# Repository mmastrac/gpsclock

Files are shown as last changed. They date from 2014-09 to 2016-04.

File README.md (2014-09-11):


========

Simple GPS clock project based on simple components from Adafruit and eBay. This consists of a number of components:

  * A backpack for the Adafruit KWA-221 2.3" digit based on the TLC-5920NT (KiCad PCB project)
  
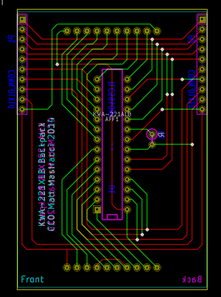
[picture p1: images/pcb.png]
pcb screenshot


  * An Arduino project that reads GPS time from the Adafruit GPS adapter and pushes it out to backpack

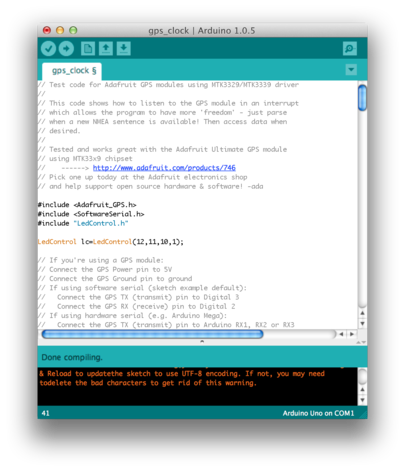
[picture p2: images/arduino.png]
arduino screenshot


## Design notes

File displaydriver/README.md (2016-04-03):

This is the AVR code that runs the display driver

The attiny85 can be programmed like so, note the lfuse settings for the external clock:

make clean && make && avrdude -p t85 -c avrispv2 -P /dev/cu.usbmodem00028541 -U flash:w:main.hex -U lfuse:w:0xe2:m

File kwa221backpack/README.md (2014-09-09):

TODO:

  * Contribute TLC-5940NT back to open-projects
  * Move all routed traces underneath footprint of LED

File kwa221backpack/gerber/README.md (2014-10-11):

These are the files you submit to the board manufacturing service.

v1
==

Original, manufactured via Seeedstudios. 

Deficiencies:
  * No mounting holes
  * Headers hit the lip on the LED display, making it tough to align
  * No way to easily test value of IREF resistor when using trim pots

v2
==

(in progress)

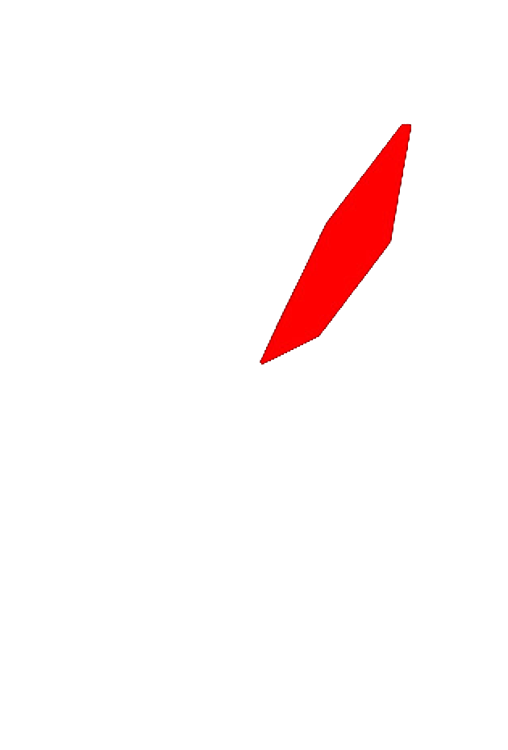
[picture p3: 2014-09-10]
fontmaker/display/K.png

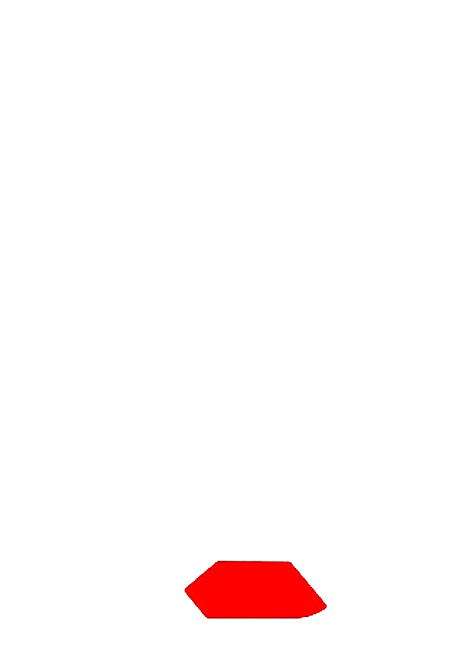
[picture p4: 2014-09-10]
fontmaker/display/D2.png

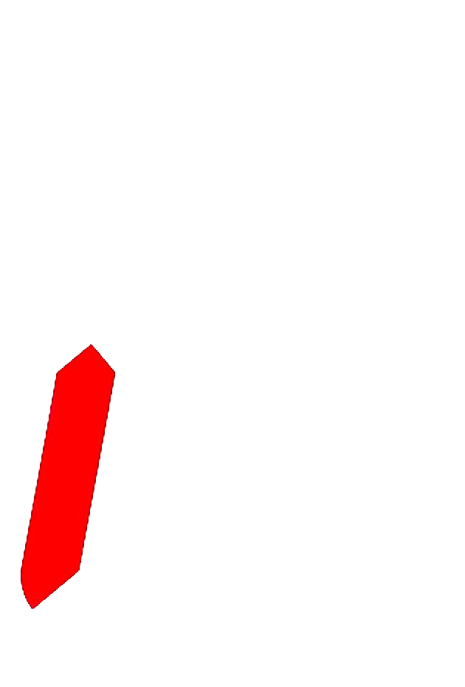
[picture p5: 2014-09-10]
fontmaker/display/E.png

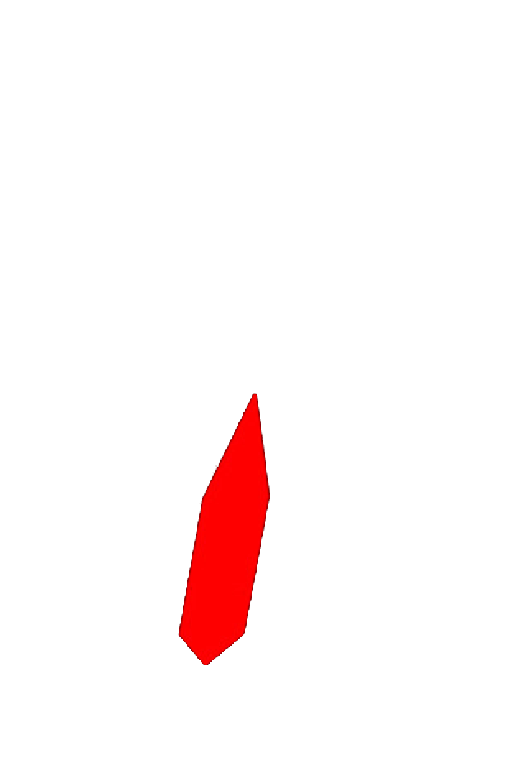
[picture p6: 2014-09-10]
fontmaker/display/M.png

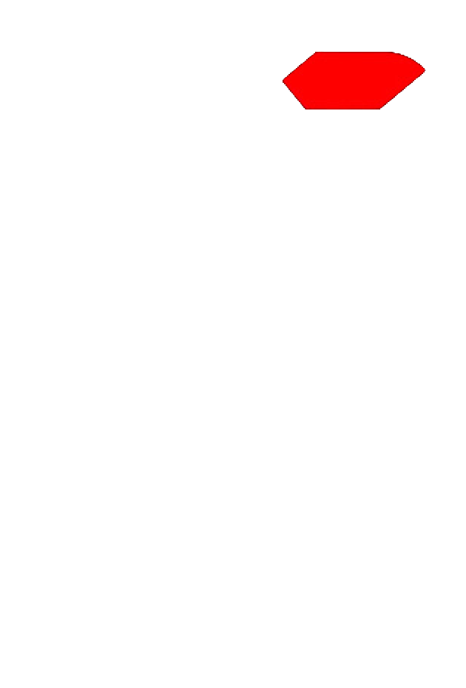
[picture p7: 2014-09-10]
fontmaker/display/A2.png

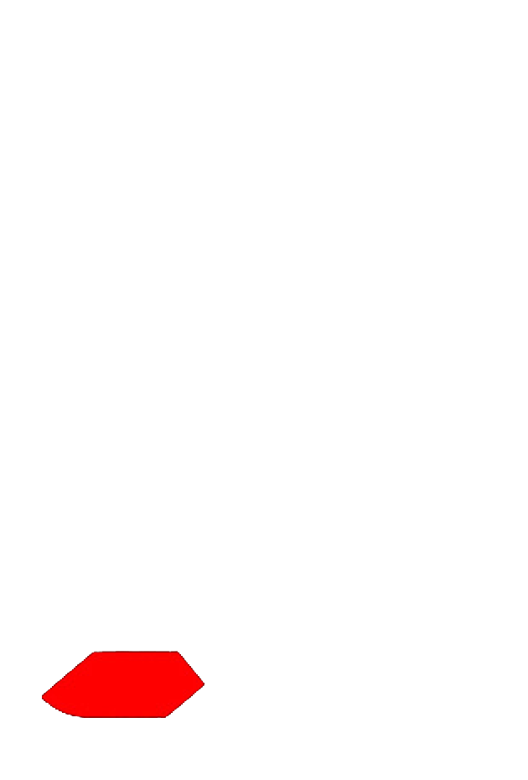
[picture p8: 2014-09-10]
fontmaker/display/D1.png

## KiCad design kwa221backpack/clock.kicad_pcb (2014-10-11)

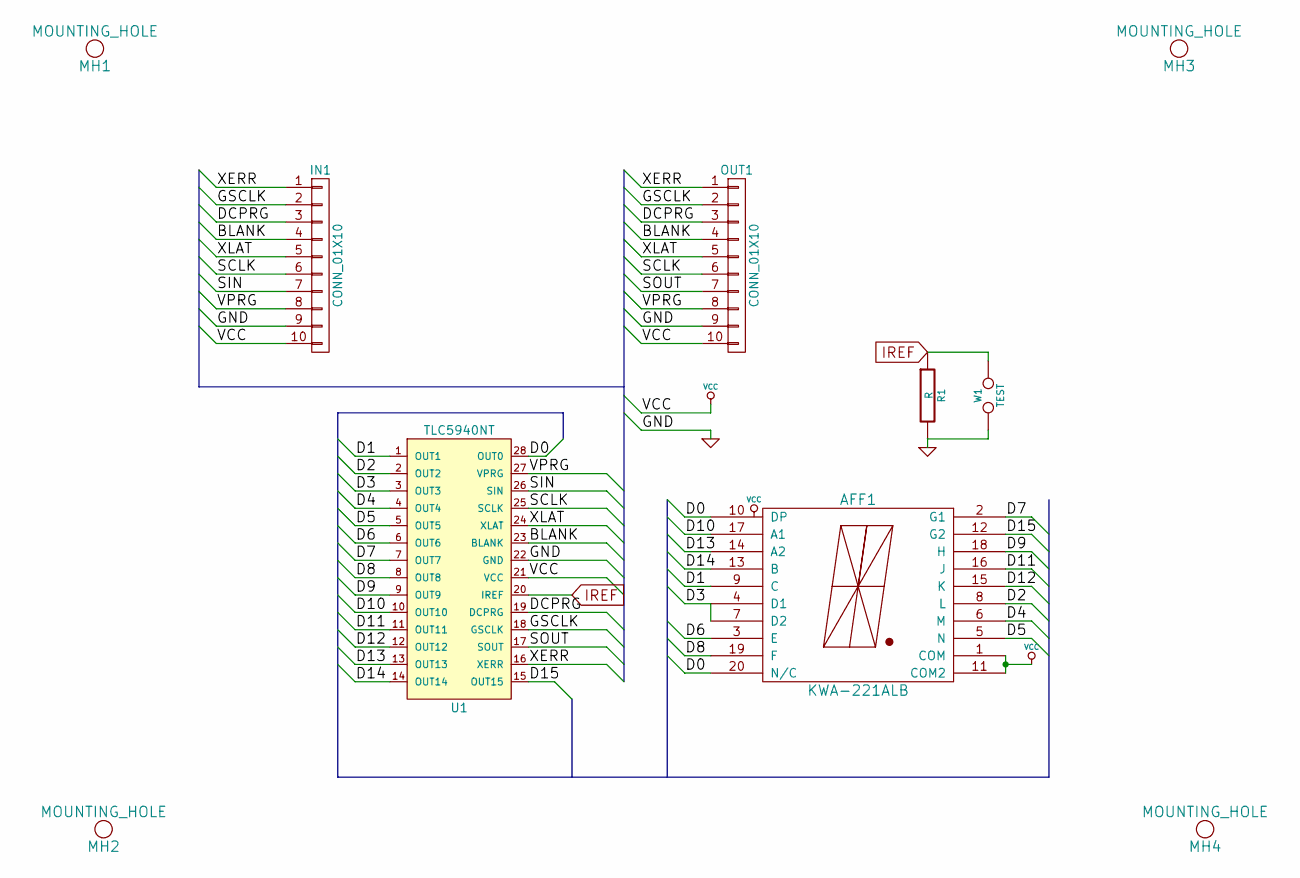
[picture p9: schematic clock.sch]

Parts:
AFF1: KWA-221ALB
IN1: CONN_01X10
MH1, MH2, MH3, MH4: MOUNTING_HOLE
OUT1: CONN_01X10
R1: R
U1: TLC5940NT
W1: TEST

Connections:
/BLANK: IN1.4, OUT1.4, U1.23 (BLANK)
/D0: AFF1.10 (DP), AFF1.20 (N/C), U1.28 (OUT0)
/D1: AFF1.9 (C), U1.1 (OUT1)
/D2: AFF1.8 (L), U1.2 (OUT2)
/D3: AFF1.4 (D1), AFF1.7 (D2), U1.3 (OUT3)
/D4: AFF1.6 (M), U1.4 (OUT4)
/D5: AFF1.5 (N), U1.5 (OUT5)
/D6: AFF1.3 (E), U1.6 (OUT6)
/D7: AFF1.2 (G1), U1.7 (OUT7)
/D8: AFF1.19 (F), U1.8 (OUT8)
/D9: AFF1.18 (H), U1.9 (OUT9)
/D10: AFF1.17 (A1), U1.10 (OUT10)
/D11: AFF1.16 (J), U1.11 (OUT11)
/D12: AFF1.15 (K), U1.12 (OUT12)
/D13: AFF1.14 (A2), U1.13 (OUT13)
/D14: AFF1.13 (B), U1.14 (OUT14)
/D15: AFF1.12 (G2), U1.15 (OUT15)
/DCPRG: IN1.3, OUT1.3, U1.19 (DCPRG)
/GSCLK: IN1.2, OUT1.2, U1.18 (GSCLK)
/SCLK: IN1.6, OUT1.6, U1.25 (SCLK)
/SIN: IN1.7, U1.26 (SIN)
/SOUT: OUT1.7, U1.17 (SOUT)
/VPRG: IN1.8, OUT1.8, U1.27 (VPRG)
/XERR: IN1.1, OUT1.1, U1.16 (XERR)
/XLAT: IN1.5, OUT1.5, U1.24 (XLAT)
GND: IN1.9, OUT1.9, R1.2, U1.22 (GND), W1.1
IREF: R1.1, U1.20 (IREF), W1.2
VCC: AFF1.1 (COM), AFF1.11 (COM2), IN1.10, OUT1.10, U1.21 (VCC)

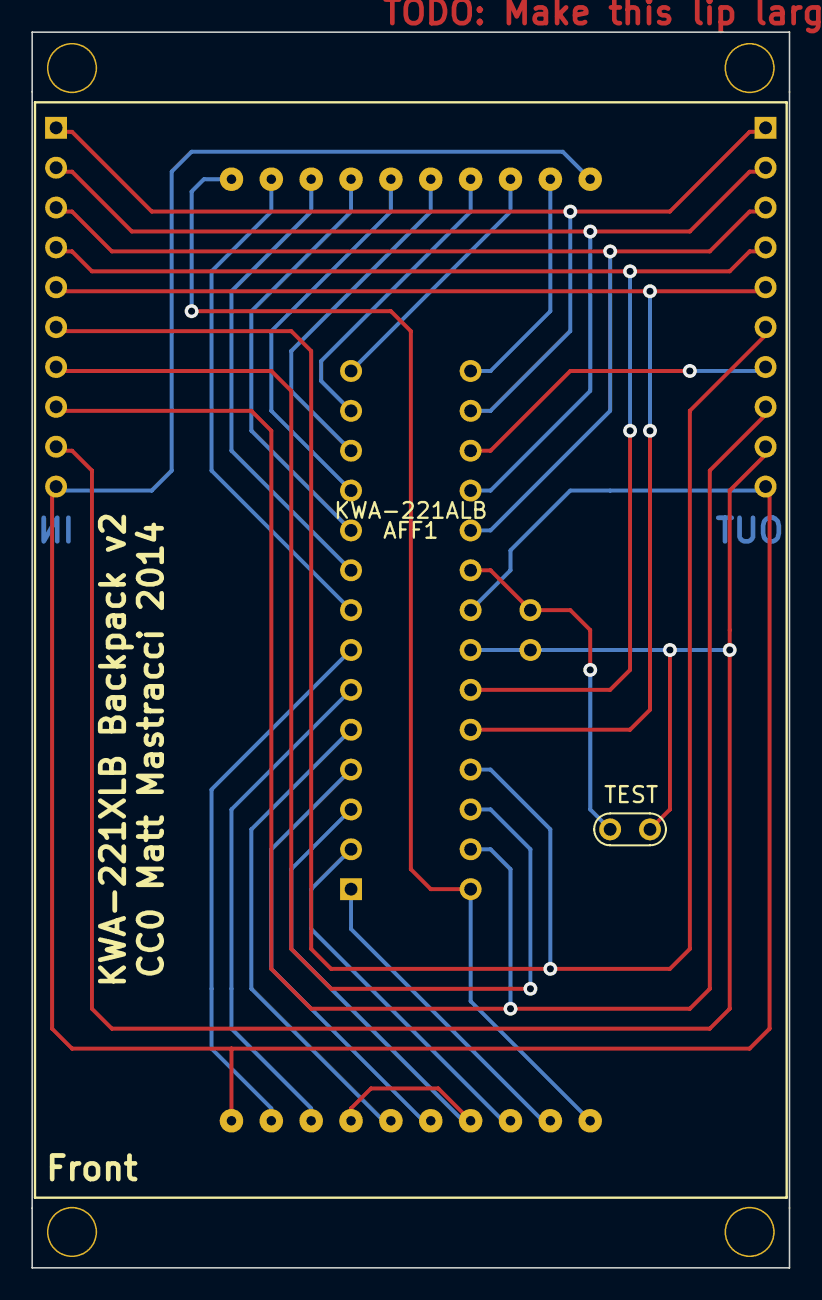
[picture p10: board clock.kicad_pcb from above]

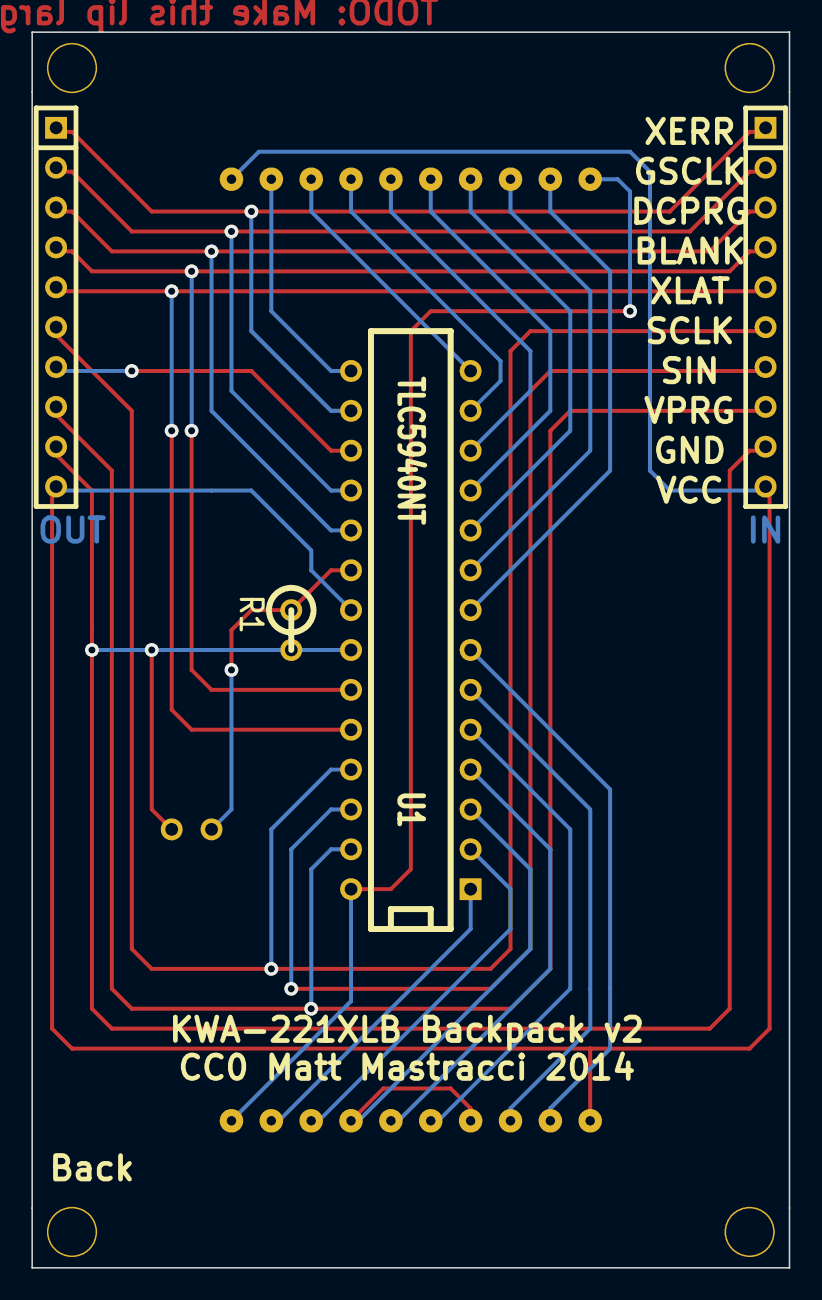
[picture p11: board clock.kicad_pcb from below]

Board: 2 copper layers, 48.3 x 78.7 mm, 10 parts (4 on the bottom side), 28 nets.

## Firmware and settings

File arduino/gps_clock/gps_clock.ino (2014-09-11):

// Test code for Adafruit GPS modules using MTK3329/MTK3339 driver
//
// This code shows how to listen to the GPS module in an interrupt
// which allows the program to have more 'freedom' - just parse
// when a new NMEA sentence is available! Then access data when
// desired.
//
// Tested and works great with the Adafruit Ultimate GPS module
// using MTK33x9 chipset
//    ------> http://www.adafruit.com/products/746
// Pick one up today at the Adafruit electronics shop 
// and help support open source hardware & software! -ada

#include <Adafruit_GPS.h>
#include <SoftwareSerial.h>
#include "LedControl.h"

LedControl lc=LedControl(12,11,10,1);

// If you're using a GPS module:
// Connect the GPS Power pin to 5V
// Connect the GPS Ground pin to ground
// If using software serial (sketch example default):
//   Connect the GPS TX (transmit) pin to Digital 3
//   Connect the GPS RX (receive) pin to Digital 2
// If using hardware serial (e.g. Arduino Mega):
//   Connect the GPS TX (transmit) pin to Arduino RX1, RX2 or RX3
//   Connect the GPS RX (receive) pin to matching TX1, TX2 or TX3

// If you're using the Adafruit GPS shield, change 
// SoftwareSerial mySerial(3, 2); -> SoftwareSerial mySerial(8, 7);
// and make sure the switch is set to SoftSerial

// If using software serial, keep these lines enabled
// (you can change the pin numbers to match your wiring):
SoftwareSerial mySerial(3, 2);

//Adafruit_GPS GPS(&mySerial);
// If using hardware serial (e.g. Arduino Mega), comment
// out the above six lines and enable this line instead:
Adafruit_GPS GPS(&mySerial);


// Set GPSECHO to 'false' to turn off echoing the GPS data to the Serial console
// Set to 'true' if you want to debug and listen to the raw GPS sentences. 
#define GPSECHO  true

// this keeps track of whether we're using the interrupt
// off by default!
boolean usingInterrupt = false;
void useInterrupt(boolean); // Func prototype keeps Arduino 0023 happy

void setup()  
{
  lc.setIntensity(0,8);
  lc.clearDisplay(0);
  lc.shutdown(0,false);

  // connect at 115200 so we can read the GPS fast enough and echo without dropping chars
  // also spit it out
  Serial.begin(115200);
  Serial.println("Adafruit GPS library basic test!");

  // 9600 NMEA is the default baud rate for Adafruit MTK GPS's- some use 4800
  GPS.begin(9600);
  
  GPS.sendCommand("$PMTK104*37");
  
  // uncomment this line to turn on RMC (recommended minimum) and GGA (fix data) including altitude
  GPS.sendCommand(PMTK_SET_NMEA_OUTPUT_RMCGGA);
  // uncomment this line to turn on only the "minimum recommended" data
  //GPS.sendCommand(PMTK_SET_NMEA_OUTPUT_RMCONLY);
  // For parsing data, we don't suggest using anything but either RMC only or RMC+GGA since
  // the parser doesn't care about other sentences at this time
  
  // Set the update rate
  GPS.sendCommand(PMTK_SET_NMEA_UPDATE_1HZ);   // 1 Hz update rate
  // For the parsing code to work nicely and have time to sort thru the data, and
  // print it out we don't suggest using anything higher than 1 Hz

  // Request updates on antenna status, comment out to keep quiet
  GPS.sendCommand(PGCMD_ANTENNA);

  // the nic e thing about this code is you can have a timer0 interrupt go off
  // every 1 millisecond, and read data from the GPS for you. that makes the
  // loop code a heck of a lot easier!
  useInterrupt(true);

  delay(1000);
  // Ask for firmware version
  mySerial.println(PMTK_Q_RELEASE);
}


// Interrupt is called once a millisecond, looks for any new GPS data, and stores it
SIGNAL(TIMER0_COMPA_vect) {
  char c = GPS.read();
  // if you want to debug, this is a good time to do it!
#ifdef UDR0
  if (GPSECHO)
    if (c) UDR0 = c;  
    // writing direct to UDR0 is much much faster than Serial.print 
    // but only one character can be written at a time. 
#endif
}

void useInterrupt(boolean v) {
  if (v) {
    // Timer0 is already used for millis() - we'll just interrupt somewhere
    // in the middle and call the "Compare A" function above
    OCR0A = 0xAF;
    TIMSK0 |= _BV(OCIE0A);
    usingInterrupt = true;
  } else {
    // do not call the interrupt function COMPA anymore
    TIMSK0 &= ~_BV(OCIE0A);
    usingInterrupt = false;
  }
}

uint32_t timer = millis();
void loop()                     // run over and over again
{
  // in case you are not using the interrupt above, you'll
  // need to 'hand query' the GPS, not suggested :(
  if (! usingInterrupt) {
    // read data from the GPS in the 'main loop'
    char c = GPS.read();
    // if you want to debug, this is a good time to do it!
    if (GPSECHO)
      if (c) Serial.print(c);
  }
  
  // if a sentence is received, we can check the checksum, parse it...
  if (GPS.newNMEAreceived()) {
    // a tricky thing here is if we print the NMEA sentence, or data
    // we end up not listening and catching other sentences! 
    // so be very wary if using OUTPUT_ALLDATA and trytng to print out data
    //Serial.println(GPS.lastNMEA());   // this also sets the newNMEAreceived() flag to false
  
    if (!GPS.parse(GPS.lastNMEA()))   // this also sets the newNMEAreceived() flag to false
      return;  // we can fail to parse a sentence in which case we should just wait for another
  }

  // if millis() or timer wraps around, we'll just reset it
  if (timer > millis())  timer = millis();

  boolean hasTime = (GPS.hour != 0 && GPS.hour != 23) 
    || GPS.year != 80 
    || GPS.fix;

  if (hasTime) {
    lc.setLed(0,7,0,false);
  } else {
    lc.setLed(0,7,0,(millis() % 2000) < 1750);
  }
  
  if (millis() - timer > 500) { 
    timer = millis(); // reset the timer

    Serial.print("\nTime: ");
    Serial.print(GPS.hour, DEC); Serial.print(':');
    Serial.print(GPS.minute, DEC); Serial.print(':');
    Serial.print(GPS.seconds, DEC); Serial.print('.');
    int hour = (GPS.hour + 24 - 6) % 12;
    
    if (hasTime) {
      int lines[] = {
        0, 0, 0, 0, B01011011, B00000101, B00001101, B00010111, 0, B01011110, B11100111, B11011011, 0, 0, 0
      };
      
      for (int i = 0; i < 4; i++) {
        lc.setRow(0,i,lines[millis() / 500 % 12 + i]);
      } 
    } else {
      if (hour >= 10)
        lc.setDigit(0,0,hour / 10,false);
      else
        lc.setRow(0,0,0);
      lc.setDigit(0,1,hour % 10,false);
      lc.setDigit(0,2,GPS.minute / 10,false);
      lc.setDigit(0,3,GPS.minute % 10,false);
    }
    
    Serial.println(GPS.milliseconds);
    Serial.print("Date: ");
    Serial.print(GPS.day, DEC); Serial.print('/');
    Serial.print(GPS.month, DEC); Serial.print("/20");
    Serial.println(GPS.year, DEC);
    Serial.print("Fix: "); Serial.print((int)GPS.fix);
    Serial.print(" quality: "); Serial.println((int)GPS.fixquality); 
    if (GPS.fix) {
      Serial.print("Location: ");
      Serial.print(GPS.latitude, 4); Serial.print(GPS.lat);
      Serial.print(", "); 
      Serial.print(GPS.longitude, 4); Serial.println(GPS.lon);
      
      Serial.print("Speed (knots): "); Serial.println(GPS.speed);
      Serial.print("Angle: "); Serial.println(GPS.angle);
      Serial.print("Altitude: "); Serial.println(GPS.altitude);
      Serial.print("Satellites: "); Serial.println((int)GPS.satellites);
    }
  }
}

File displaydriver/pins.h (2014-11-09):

#pragma once

/*
	Attiny85 pinouts:

	           +----+ 
	RESET   5 -|o   |-   VCC 
	DATAOUT 3 -|    |- 2 SIN
	DATAIN  4 -|    |- 1 GSCLK/SCLK
	GND       -|    |- 0 BLANK/XLAT
		       +----+
*/


// BLANK + XLAT
#define BLANK_PORT B
#define BLANK_PIN 0

// GSCLK + SCLK
#define GSCLK_PORT B
#define GSCLK_PIN 1

// SIN
#define SIN_PORT B
#define SIN_PIN 2

// DATAIN
#define DATAIN_PORT B
#define DATAIN_PIN 4

// DATAOUT
#define DATAOUT_PORT B
#define DATAOUT_PIN 3

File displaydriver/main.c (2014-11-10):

#include <stdint.h>
#include <avr/io.h>
#include <avr/interrupt.h>
#include <util/delay.h>
#include <stdlib.h>
#include <stdbool.h>
#include <avr/wdt.h>

#include "bitbang.h"
#include "sin_cycle.h"
#include "font.h"
#include "tlc5940.h"
#include "ticks.h"
#include "serial.h"
#include "pins.h"
#include "hex_digits.h"

uint8_t mode = 0;
uint8_t display[4] = { 'v', '1', '0', '0' };

uint8_t scroll_buffer[16] = { 0 };
uint8_t scrolling_counter = 0;
uint8_t scrolling_length = 0;

bool lockup = false;

void soft_reset() {
	do {
	    wdt_enable(WDTO_15MS);  
	    for(;;) {}
	} while(0);
}

void process_serial() {
	// A packet is minimum three bytes (sync, length, cmd)
	while (serial_available() >= 3) {
		uint8_t sync_byte = serial_peek(0);
		if (sync_byte != 0xff) {
			if (sync_byte == '~') {
				soft_reset();
			}

			display[0] = 'E';
			display[1] = sync_byte;
			break;
		}

		uint8_t packet_length = serial_peek(1);

		// Do we even have enough data to read the packet?
		if (serial_available() < packet_length + 2) {
			// Nope, leave the data there for the next cycle
			break;
		}

		// We're committed now
		serial_drop(2);

		uint8_t cmd = serial_read();
		packet_length--;

		switch (cmd) {
			// Set the display explictly
			case 'S': {
				for (uint8_t i = 0; i < sizeof(display); i++) {
					if (packet_length) {
						display[i] = serial_read();
						packet_length--;
					}
					else {
						display[i] = ' ';
					}
				}
				break;
			}
			// Set the scrolling buffer
			case 'B': {
				for (uint8_t i = 0; i < packet_length; i++) {
					scroll_buffer[i] = serial_read();
				}
				scrolling_length = packet_length;
				scrolling_counter = 0;
				mode = 1;
				break;
			}
			default: {
				display[0] = 'C';
				display[1] = cmd;
				break;
			}
		}
	}
}

void write_gs() {
	int gs_data_start = GS_TICKS / 8 - get_gs_data_size();
	uint8_t* gs_data = get_gs_data();

	for (int i = 0; i < GS_TICKS / 8; i++) {
		int byte;
		if (i >= gs_data_start) {
			byte = gs_data[i - gs_data_start];
		} else {
			byte = 0;
		}

		for (int j = 0; j < 8; j++) {
			int bit = byte & (1 << 7);
			byte <<= 1;

			setState(SIN, bit);
			// _delay_loop_1(2);
			setHigh(GSCLK);
			// _delay_loop_1(2);
			setLow(GSCLK);
		}
	}
}

int main(void) {
    MCUSR = 0;
    wdt_disable();

	setOutput(BLANK);
	setOutput(GSCLK);
	setOutput(SIN);
	setInput(DATAIN);
	setOutput(DATAOUT);

	setHigh(BLANK);
	setLow(GSCLK);
	setLow(SIN);

	initialize_ticks();
	initialize_serial();

	sei();

	// for (;;) {
	// 	if (serial_available()) {
	// 		uint8_t c = serial_read();
	// 		if (c == '\r') {
	// 			serial_write_string("\r\n");
	// 		} else {
	// 			serial_write(pgm_read_word(&hex[c >> 4]));
	// 			serial_write(pgm_read_word(&hex[c & 0xf]));
	// 		}
	// 	}

	// 	if (tick_epoch() != current_tick_epoch) {
	// 		// serial_write('.');
	// 		current_tick_epoch = tick_epoch();
	// 	}
	// }

	int current_cycle = 0;
	uint8_t current_tick_epoch = 0;

	for (;;) {
		_delay_us(10);

		setHigh(BLANK);
		ticks_t now = ticks();
		uint8_t tick_epoch_cycle = now.epoch;
		uint16_t current_brightness = sin_cycle(now.ticks);

		current_cycle++;

		if (!lockup) {
			if (tick_epoch_cycle != current_tick_epoch) {
				current_tick_epoch = tick_epoch_cycle;
				if (mode == 1) {
					scrolling_counter++;
					if (scrolling_counter == scrolling_length - 1) {
						mode = 0;
					}
				}
			}

			process_serial();
		}

		// display[0] = hex_hi(now.epoch);
		// display[1] = hex_lo(now.epoch);

		for (uint8_t i = 0; i < sizeof(display); i++) {
			int glyph = font((mode == 1) ? scroll_buffer[scrolling_counter + i] : display[i]);
			for (int j = 0; j < 16; j++) {
				if (glyph & (1 << j)) {
					set_channel_gs(j + i * 16, GS_MAX);
				} else {
					set_channel_gs(j + i * 16, 0);
				}
			}
		}

		set_channel_gs(16, current_brightness);
		setLow(BLANK);

		_delay_us(10);

		write_gs();
	}

	return 0;
}

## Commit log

2014-09-09 First (nearly-routed) version of a board for the Adafruit 2.3" display
    [clock.kicad_pcb, clock.sch]
2014-09-09 Move these files to a subdirectory
    [clock.kicad_pcb, clock.sch]
2014-09-09 Adding a .gitignore for KiCad bak files
2014-09-09 Re-generate PCB
    [clock.sch]
2014-09-09 Re-order pins on header to simplify chip routing
    [clock.kicad_pcb, clock.sch]
2014-09-09 Moving the headers up -- not sure I like this
    [clock.kicad_pcb]
2014-09-09 Moving the top traces closer to the IC
    [clock.kicad_pcb]
2014-09-09 Managed to route all the traces under the LED
    [clock.kicad_pcb]
2014-09-09 More tweaking, allow 3D to render better
    [clock.kicad_pcb]
2014-09-10 Export Gerber/VRML
    [clock.kicad_pcb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]
2014-09-10 pcb png
2014-09-10 Adding really basic Arduino test sketch
2014-09-10 Clean out old VRML/SVG files. Clean up PCB.
    [clock.kicad_pcb]
2014-09-10 Generate gerber files. Adding fontmaker
    [clock-B_Cu.gbl, clock-B_Mask.gbs, clock-B_SilkS.gbo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]
2014-09-11 Add screenshot for arduino, resize images
2014-09-11 The 7 was bugging me. Check in a compiling version of the GPS prototype.
    [gps_clock.ino]
2014-09-11 Adding framework for tzgen -- the tools required to generate tz data for auto-setting tz
2014-09-14 Ensure that we minimize ref chains where possible
2014-10-11 Update schematic for v2: mounting holes and test point to measure iref resistor
    [clock.kicad_pcb, clock.sch]
2014-10-11 Moving outputs to a v1 directory so we can eventually generate a v2
    [clock-B_Cu.gbl, clock-B_Mask.gbs, clock-B_SilkS.gbo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]
2014-10-18 Rewrite macros to reduce boilerplate. Use a timer for the source of the LED brightness.
2014-10-19 Removing the last of the glitches by allowing the clocked-in data to settle
    [main.c]
2014-10-20 Add the beginning of a software UART
2014-10-20 Off-by-one error in the serial code
    [main.c, serial.c]
2014-11-07 Adding self-calibration over serial
2014-11-09 Serial send and receive on interrupts
2014-11-09 Add spurious pin change detected
2014-11-09 By making TIMER1_OVF less expensive, serial becomes more reliable
2014-11-10 Rewrite timers to use lock-free approach
2016-04-03 Correct fuse settings
